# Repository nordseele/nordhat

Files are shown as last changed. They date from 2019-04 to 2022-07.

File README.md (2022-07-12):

# Nordhat & audio expansion board

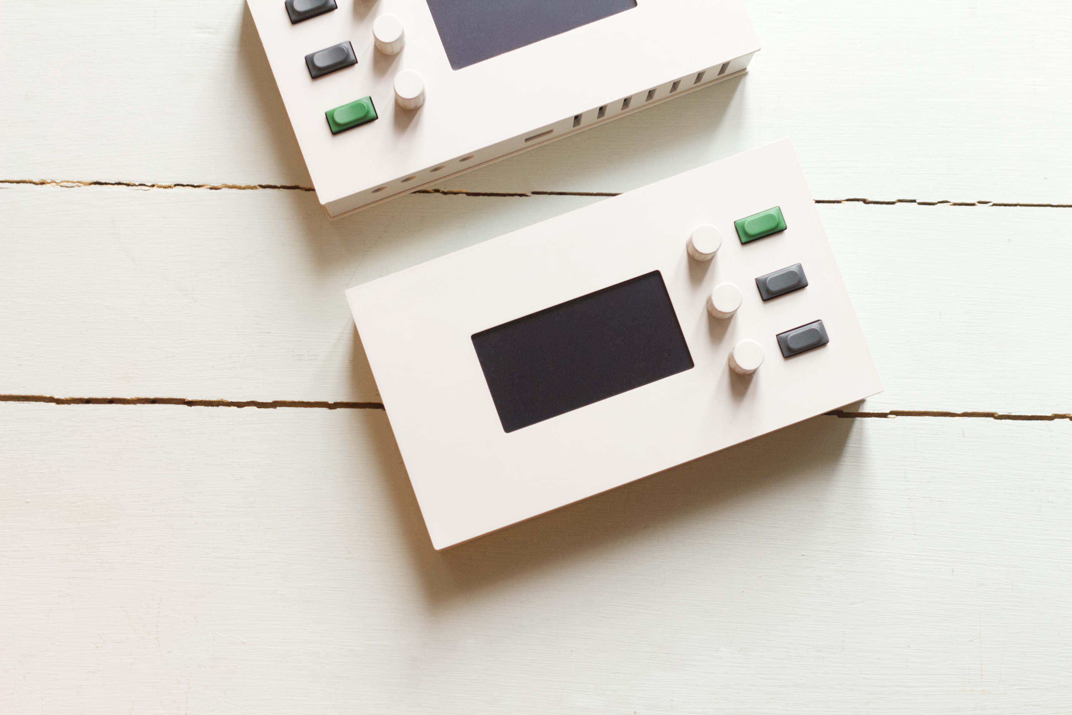
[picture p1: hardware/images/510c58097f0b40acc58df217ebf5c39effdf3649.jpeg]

Nordhat Rev 2 / custom "DR" prototypes

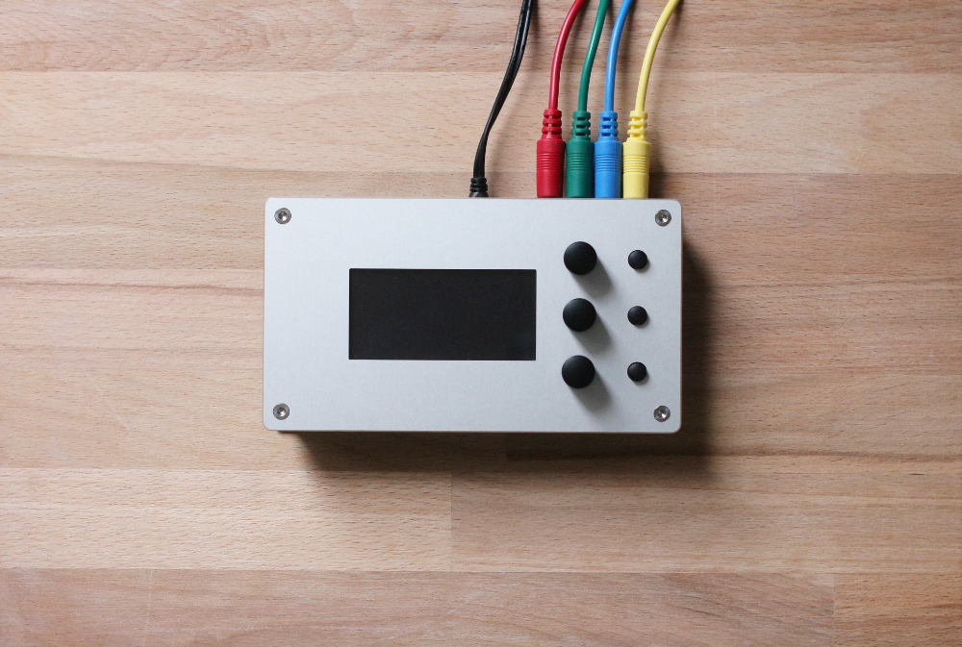
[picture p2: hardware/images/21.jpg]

Nordhat rev 1 prototype

Please read the [Notes](hardware/notes.md)

24/06/19: ***This board is probably NOT compatible with the new Raspberry Pi 4. The position of the Ethernet socket and USB sockets have changed in this latest revision of the PI and the Nordhat main PCB might not be adapted anymore.*** 

### Bill of material
[Main board](hardware/bom/BOM_mainboard_nordhat.csv)

[Expansion board](hardware/bom/BOM_expansion_board_nordhat.csv)

### Build

[Build](hardware/build.md) instructions

### Install

[Install](files/install.md) (Norns)

#### More infos and details

https://llllllll.co/t/norns-shield-case-designs/30347/333?u=nordseele

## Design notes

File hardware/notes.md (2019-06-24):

# Rev 3 Notes

## Before you start...

### Disclaimer
You must have a prior experience building electronic projects, soldering, etc. The tools (soldering iron, etc) used for building such electronic project can potentially be dangerous. This "DIY" project is not "beginner friendly". All the things learned and tested during the construction of this prototype are reflected here, these informations are provided "as is". If you have been provided with a set of PCB of this 'nordhat' or 'nornshat' (name of the early revisions) project, it is still a prototype and is still in development. You're building it at your own risk.

You'll find the references on the silkscreen and in the BOM and some additional tips and explanations on this page. If you choose another component than the one listed in the suggested BOM (encoders, jack connectors, etc) you should verify that the footprint and pin-out match, again you do this at your own risk.

***The actual Nordhat board is probably NOT compatible with the new Raspberry Pi 4. The position of the Ethernet socket and USB sockets have changed in this latest revision of the PI and the Nordhat main PCB might not be adapted anymore.***
---
# Hardware

### Dimensions

    Height: 84mm  
    Width: 150mm  
    Depth: 28mm  

## Headers and card to card connectors

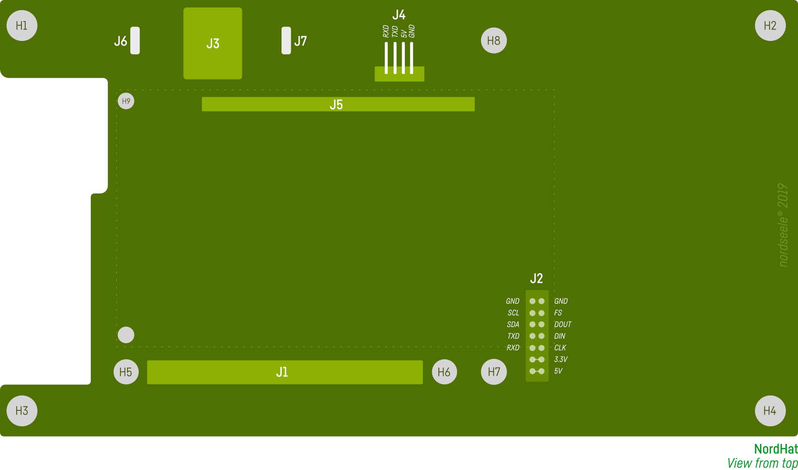
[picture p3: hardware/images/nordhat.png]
nordhat


#### J3, J7, J6 - The I2C section (middle/top of the board)
It's probably better to ***avoid soldering these connectors for now if you don't know what you're doing***, don't solder/order J3,J7,J6. This can be done later.

Edit : The I2C is already used for the DAC, this jack output will probably never be used simultaneously.

For now, this section has not been tested and has no utility. If you choose to solder the jack connector despite this recommendation, you should ***NEVER connect a midi jack or audio jack to this plug***. If you solder the stereo jack connector, it can be soldered either on top or on the bottom of the board (see silkscreen) but it's recommended to solder it on the bottom. For J7 and J6, cut two pins from a male 2.54 breakable pin strip like the reference suggested. (Order only one if you order the Adafruit 392, it’s a pack of 10 pieces)

#### J4 - UART 4 pins angled header
If you're not planning to use the UART header, don't solder/order J4, it can also be done later if you change your mind. If you solder it on, this header should be placed/soldered on top of the board (even if the silkscreen is printed on the bottom). This header can be used with the Adafruit 954 cable. You should ***NEVER CONNECT THE 5V pin if the Raspberry Pi is powered from USB.***

#### J2, 02x07 pins - expansion board header
You should solder this 14 positions 2 rows header ***before soldering the OLED*** display. It would be impossible or very difficult to solder this afterwards.
#### J5 - OLED Header
Cut twenty pins from a male 2.54 breakable pin strip (see Adafruit 392 pack, as mentioned above)

____

## OLED display

Solder the expansion board header (J2) before soldering the OLED display.

___
## Buttons and encoders

### Buttons / Key switches
We’re using low actuation force key switches, but feel free to use another actuation force, in the same APEM 5E series. Note that you could use the 5G series which has the same footprint and a larger choice of caps available, but you'll have to modify the cutout (larger holes) of the top panel in consequence.

### Button caps
1SS, the only caps available for the 5E series. They're available in **multiple colors** and height but 7mm is the recommended height. read the data sheet of the manufacturer to find out how to adjust the reference. Adjust height depending on the thickness of the panel etc. Try different heights eventually. ***These caps are made for the APEM 5E series ONLY***.

### Encoders
We’re using encoders without detent and without switch with T18 shaft. The shortest available in this series.
Use PEC11R-4015F-N0024 if you want a D-Shaft.
### Encoder knobs
Use what you want, modify your choice of encoder/shaft in consequence. The encoders knobs used on the "Nord Hat" prototype are not available to buy.  
___
## Standoffs

The NordHat prototype uses M3 rounded steel standoffs from the **WA-SMSI series made by Würth Elektronik** for H1, H2, H3, H4. The mounting holes have been specifically designed for these standoffs. The diameter of the holes is 4.4mm. If you do not use the WA-SMSI standoffs and prefer using some regular HEX standoffs instead, make sure they have a diameter of 6mm minimum. Use regular M2.5 hex standoffs for non-visible / internal mounting holes (H5, H6, H9, H8, H7)

It is recommended to use the following dimensions, these are the minimum heights. The Raspberry should not be in contact with the bottom panel. There should be 1 or 2mm of clearance between the panel and and the bottom of the RPI, especially if you're using an aluminium panel.

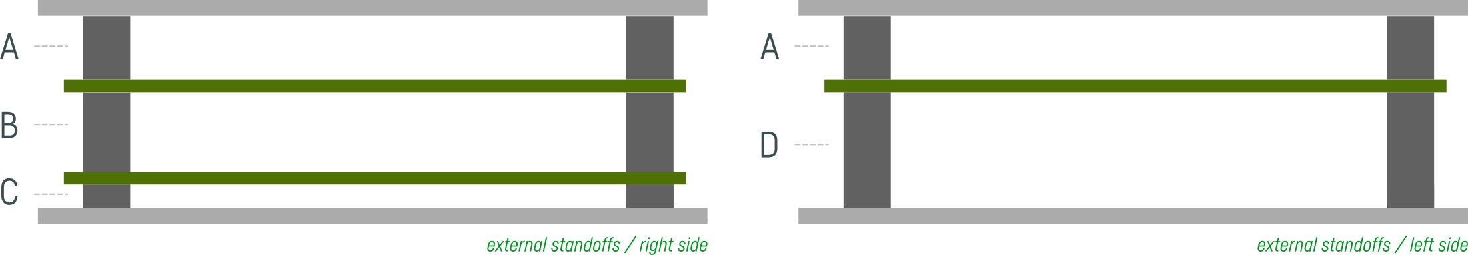
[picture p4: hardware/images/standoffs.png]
standoffs


| holes (h) | position | length  | type  | thread | quantity | sku
| :---: | :---: |:---: | :-----: | :---: | :---: | :----:
| 1, 2, 3, 4 | A | 7mm | FF  | M3 | 4 | WA-SMSI 9774070360R
| 1, 3 | D  | 15mm |  FF | M3  | 2 | WA-SMSI 9774150360R
| 5, 6  | RPI | 11mm  | FF  | M2.5 | 3 | use hex
| 9 | RPI | 11mm  | MF  | M2.5 | 3 | use hex
| 8, 7 | EXP | 10mm  | FF  | M2.5 | 2 | use hex
| 2, 4 | C | 3mm |  FF | M3  | 2 | WA-SMSI 9774030360R
| 2, 4 | B | 10mm |  FF | M3  | 2 | WA-SMSI 9774100360R

### Additional Hardware used for assembling the standoffs
Different possible combinations. Get these lines:
- ***Headless screws M3 8mm***   
- ***M2.5 6mm screws***
- ***Flat head screws M3 10mm and 6mm (Use normal head if your top panel doesn't have countersunk holes)***
- ***M2.5 nuts***

___
## Panels and screen protection
Two sets of files (dxf and fpd) are provided for making the top and bottom panels. They have countersunk holes and chamfer. If you want to make acrylic panels you'll have to edit the files to remove the chamfer and countersinks. The recommended thickness is 2mm. The viewing angle of the OLED display will be affected if the thickness is more than 2mm.

It is recommended to use a screen protection made of Perspex/ plexiglas. Less than 1mm thick. It is placed between the top panel and the display. Use double sided adhesive tape to attach it. The dimensions should be 4cm x 7cm maximum.
____

## GPIO

### Keys GPIO

- K1 : GPIO 06
- K2 : GPIO 27
- K3: GPIO 23

### Encoders GPIO

- E1A : GPIO 26  
  E1B : GPIO 13  

- E2A : GPIO 05  
  E2B : GPIO 22  

- E3A : GPIO 04  
  E3B : GPIO 17

### OLED display

- Reset : GPIO 25
- DC : GPIO 24

### UART

Using the Adafruit 954 cable:
- white lead TX
- green lead RX
- black lead GND
- ***DO NOT connect the red lead if the Pi is powered from USB !***

  `screen /dev/cu.usbserial* 115200`
____

___
##### Nordseele 2018 2019.

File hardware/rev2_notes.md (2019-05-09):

# Notes

These notes concern the Rev2 boards only (prior to Nordhat)

# Before you start...
### Disclaimer
You must have a prior experience building electronic projects, soldering, etc. The tools (soldering iron, etc) used for building such electronic project can be dangerous. This is not a beginner "DIY" project. All the things learned and tested during the construction of this prototype are reflected here, these informations are provided "as is". If you have been provided with a set of PCB of this 'nordhat' or 'nornshat' (name of the early revisions) project, it is still a prototype and is still in development. You're building it at your own risk.

You'll find the references on the silkscreen and in the BOM and some additional tips and explanations on this page. If you choose another component than the one listed in the suggested BOM (encoders, jack connectors, etc) you should verify that the footprint and pin-out match, again you do this at your own risk.

# Important advice

DO NOT solder the OLED display until all these steps are done. A certain chronology has to be respected. Some headers and standoffs are partially hidden under the OLED display. Before soldering this display, you need to solder the header ***J2*** and you need to mount a 11m standoff on ***H8*** (bottom).

---
# Hardware

### Dimensions

    Height: 84mm  
    Width: 150mm  
    Depth: 28mm  

## Headers and card to card connectors

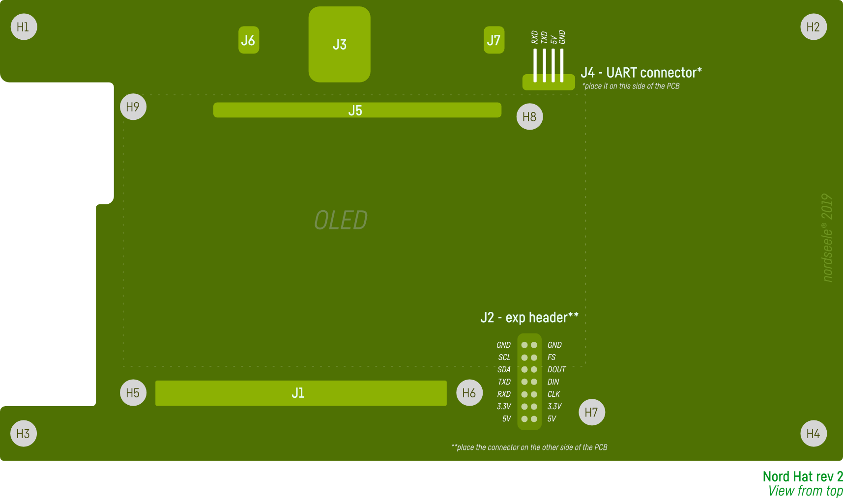
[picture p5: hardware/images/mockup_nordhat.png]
mockup headers and mounting holes


### J3, J7, J6 - The I2C section (middle/top of the board)
It's probably better to ***avoid soldering these connectors for now if you don't know what you're doing***, don't solder/order J3,J7,J6. This can be done later. For now, this section has not been tested and has no utility. If you choose to solder the jack connector despite this recommendation, you should ***NEVER connect a midi jack or audio jack to this plug***. If you solder the stereo jack connector, it can be soldered either on top or on the bottom of the board (see silkscreen) but it's recommended to solder it on the bottom. For J7 and J6, cut two pins from a male 2.54 breakable pin strip like the reference suggested. (Order only one if you order the Adafruit 392, it’s a pack of 10 pieces)

### J4 - UART 4 pins angled header
If you're not planning to use the UART header, don't solder/order J4, it can also be done later if you change your mind. If you solder it on, this header should be placed/soldered on top of the board (even if the silkscreen is printed on the bottom). This header can be used with the Adafruit 954 cable. You should ***NEVER CONNECT THE 5V pin if the Raspberry Pi is powered from USB.***

### J2, 02x07 pins - expansion board header
If you're planning to use the audio expansion board or if you need to access the GPIO )written on the bottom silkscreen) for any other purpose, ***you should solder this 14 positions 2 rows header before you solder the OLED display. It would be impossible or very difficult to solder this afterwards.***
### J5 - OLED Header
Cut twenty pins from a male 2.54 breakable pin strip (see Adafruit 392 pack, as mentioned above)

____

## OLED display

### A small modification of the NHD-2.7-12864WDW3 is required if you want to want to keep the oled display very low, flush to the main board PCB. If you prefer not doing this modification, you will have have to mount standoffs under the display. This Oled display has tiny black legs under it and these legs could be in contact with the expansion header.  

So you need to bend two of these legs (bottom right and top right when you face the display). If this modification is not done, one of these legs could possibly be in contact with the **J2** and the other one would hide the hole **h8** thus preventing the possibility of mounting a standoff there.

***Use some pliers and proceed very carefully ! Do this at your own risk***

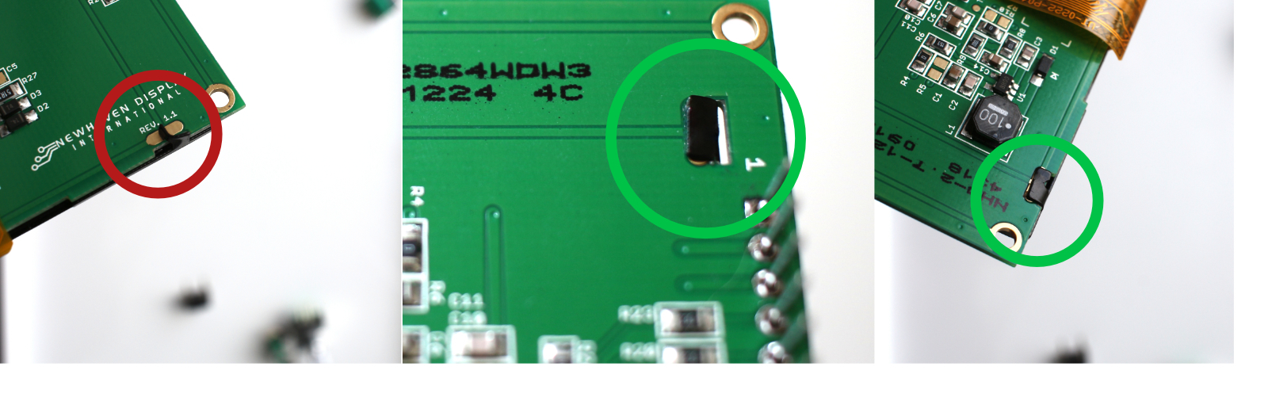
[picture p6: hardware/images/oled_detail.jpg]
bend the legs of the oled


### You should solder the various connectors and mount the standoff h8 BEFORE soldering the Oled display

___
## Buttons and encoders

### Buttons / Key switches
We’re using low actuation force key switches, but feel free to use another actuation force, in the same APEM 5E series. Note that you could use the 5G series which has the same footprint and a larger choice of caps available, but you'll have to modify the cutout (larger holes) of the top panel in consequence.

### Button caps
1SS, the only caps available for the 5E series. They're available in **multiple colors** and height. read the data sheet of the manufacturer to find out how to adjust the reference. Adjust height depending on the thickness of the panel etc. Try different heights eventually. ***These caps are made for the APEM 5E series ONLY***.

### Encoders
We’re using encoders without detent and without switch with T18 shaft. The shortest available in this series.
Use PEC11R-4015F-N0024 if you want a D-Shaft terminaison.
### Encoder knobs
Use what you want, modify your choice of encoder/shaft terminaison in consequence. The encoders knobs used on the "Nord Hat" prototype are not available to buy.  
___
## Standoffs
It is recommended to use the following dimensions, these are the minimum heights. The Raspberry should not be in contact with the bottom panel. There should be 1 or 2mm of clearance between the panel and and the bottom of the RPI, especially if you're using an aluminium panel.

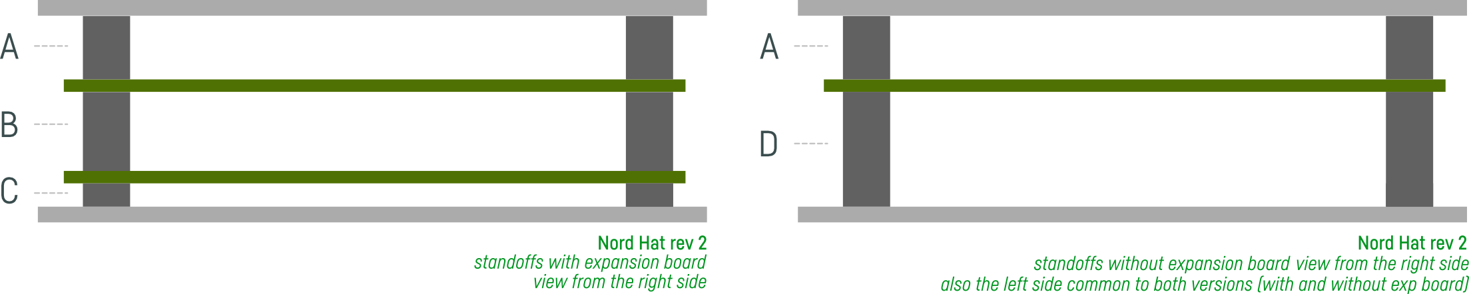
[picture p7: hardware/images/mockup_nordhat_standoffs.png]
mockup standoffs


### With expansion board

| holes (h) | position | length  | type  | thread | quantity |
| :---: | :---: |:---: | :-----: | :---: | :---: |
| 1, 2, 3, 4 | A | 7mm | FF  | M3 | 4 |
| 1, 3 | D  | 15mm |  FF | M3  | 2 |
| 5, 6, 9 | RPI | 11mm  | MF  | M2.5 | 3 |
| 8, 7 | EXP | 10mm  | FF  | M2.5 | 2 |
| 2, 4 | C | 3mm |  FF | M3  | 2 |
| 2, 4 | B | 10mm |  FF | M3  | 2 |

### Without expansion board
| holes (h) | position | length  | type  | thread | quantity |
| :---: | :---: |:---: | :-----: | :---: | :---: |
| 1, 2, 3, 4 | A | 7mm | FF  | M3 | 4 |
| 1, 2, 3, 4 | D | 15mm |  FF | M3  | 4 |
| 5, 6, 9 | RPI | 11mm  | MF  | M2.5 | 3 |
|8  | OPT  |  10mm | FF  | M2.5  |  1 |

> Even if you don't use an expansion board now, if you want to attach one someday it is recommended to mount the ***H8 standoff*** (noted OPT in the table above). It won't be possible to attach it once the OLED is soldered on. This has to be done before soldering the OLED.

### Hardware used for assembling the standoffs
Different possible combinations. Get these lines:
- ***Headless screws M3 8mm***    
- ***Flat head screws M3 10mm and 6mm (Use normal head if your top panel doesn't have countersunk holes)***
- ***M2.5 nylon washers***  
- ***M2.5 nuts***

#### More infos about the standoffs
The Nord Hat prototype use rounded  steel standoffs of the **WA-SMSI series made by Würth Elektronik**. If you wish to use them, you will need to drill some mounting holes of the PCB (diameter 4.4mm H1, 2, 3, 4). Do this at your own risk even though there are no traces passing too close from these holes and there's an additional margin of error of 1mm. Beware if you order these standoffs, they have a thinner 1mm high ring on top, the height of this ring supposed to be inserted into the mounting hole is not taken into account in the reference, that means that the WA-SMSI 15mm standoff is actually 15mm + 1mm (16mm). Same goes for all the references of this series (see data sheet of the manufacturer for more information).
___
## Panels and screen protection
Two sets of files (dxf and fpd) are provided for making the top and bottom panels. They have countersunk holes and chamfer. If you want to make acrylic panels you'll have to edit the files to remove the chamfer and countersinks. The recommended thickness is 2mm. The viewing angle of the OLED display will be affected if the thickness is more than 2mm.

It is recommended to use a screen protection made of Perspex/ plexiglas. Less than 1mm thick. It is placed between the top panel and the display. Use double sided adhesive tape to attach it. The dimensions should be 4cm x 7cm maximum.

##### Nordseele 2018 2019.

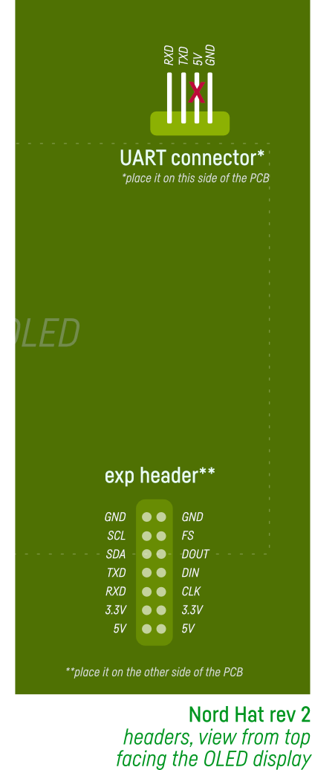
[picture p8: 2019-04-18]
hardware/images/mockup_nordhat_headers.png

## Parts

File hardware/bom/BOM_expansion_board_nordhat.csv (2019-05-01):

Id | Designator | Package | Quantity | Designation | Manufacturer ref
3 | J6 | sj1-3523 | 1 | Stereo jack 3.5 | sj1-3523
4 | J4,J5,J2,J3 | MJ_3536 | 4 | Mono jack 3.5 | MJ-3536
6 | J1 | Header_2x07_P2.54mm_Vertical | 1 | Connector | 215307-7
5 | Y1 | Crystal_HC49 | 1 | 12.288MHz | Abracon ABLS2-12.288MHZ-D4Y-T
7 | U2 | Voltage regulator | 1 | ADP150AUJZ-3.3-R7 | ADP150AUJZ-3.3-R7
8 | C17,C2,C3 | Electrolytic cap | 3 | 10uF | EEE-1EA100WR
9 | C7,C8 | Electrolytic cap | 2 | 220uF | EEEFTE221XAP
10 | C12,C13,C14,C15 | Electrolytic cap | 4 | 1u | EEE1HA010SR
11 | C1,C4,C5,C6,C11,C27,C19 | Ceramic cap_0805 | 7 | 100n | 08051C104J4T4A
13 | C16,C18 | Ceramic cap_0805 | 2 | 18p | C0805X180J5GAC7800
1 | C10,C9 | Ceramic cap_0805 | 2 | 220p | 885012007059
14 | R1,R2,R3,R4 | resistor_0805, 1% | 4 | 220R | CRCW0805220RFKEAC
2 | R10,R5,R6,R9 | resistor_0805, 1% | 4 | 5.6K | CRCW08055K60FKEAC
15 | R7,R8,R11,R12 | resistor_0805, 1% | 4 | 47K | CRCW080547K0FKEAC
16 | R13,R14 | resistor_0805, 1% | 2 | 100R | CRCW0805100RFKEAC
12 | U1 | SSOP-28 | 1 | WM8731 DAC | WM8731SEDS/RV
17 |  | Standoffs | <—> | See notes | See notes.md

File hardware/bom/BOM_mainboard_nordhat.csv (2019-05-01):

Id | Designator | Package | Quantity | Designation | Supplier and ref | Notes
 | Switches | SW_MEC_5ETH920Q | 3 | Switches | APEM 5ETH920Q | See notes.md
 | Encoders | RotaryEncoder_Bourns_Vertical | 3 | Rotary_Encoders | PEC11R-4015K-N0024 (T18) | PEC11R-4015F-N0024 for D-shaft See notes.md
 | J5 | NHD-2.7-12864WDW3_nosilk | 1 | OLED display | NHD-2.7-12864WDW3
 | J3 | SJ3523_stereo | 1 | I2C stereo jack (*) | SJ1-3523N | See notes.md
 | J7,J6 | Header 1x02_P2.54mm_Vertical | 2 | I2C jumpers (*) | Adafruit 392 | See notes.md
 | J4 | Header 1x04_P2.54mm_angled | 1 | UART header | WURTH 61300411021 | See notes.md
 | J2 | Header_2x07_P2.54mm_Vertical | 1 | Expansion header | TSW-107-07-G-D | See notes.md
 | J1 | Header_2x20_P2.54mm_Vertical | 1 | RPi GPIOS header | ADAFRUIT 2222 | See notes.md
 | J5 (B) | Header 1x20_P2.54mm_Vertical | 1 | Oled header | Adafruit 392 | See notes.md
 | D4,D3,D2,D1 | D_SOD-123 | 4 | 1N4148 | 1N4148W-7-F
 | C1,C2,C3,C4,C5,C6,C7,C8,C9 | Ceramic_capacitors 0805 | 9 | 0.1uF (100n) | 08051C104J4T4A
 | R4,R5,R6,R9,R10,R13,R14,R17,R18 | Resistors 0805_1% | 9 | 10k | CRCW080510K0FKEAC
 | R1,R2 | Resistors 0805_1% | 2 | 4.7k | CRCW08054K70FKEA
 | Button caps |  |  | Button caps | APEM 1SS09-12.0 | See notes.md
 | Encoder knobs |  |  | Undetermined | Undetermined | See notes.md
 | Raspberry Pi | Raspberry Pi 3 Model B+
 | Standoffs | Undetermined | <—> | Standoffs | See notes | See notes.md
 | The asterisk means that the corresponding line is probably optional. Read the corresponding section in « notes.md »

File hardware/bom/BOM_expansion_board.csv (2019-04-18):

Id | Designator | Package | Quantity | Designation | Manufacturer ref
3 | J6 | sj1-3523 | 1 | Stereo jack 3.5 | sj1-3523
4 | J4,J5,J2,J3 | MJ_3536 | 4 | Mono jack 3.5 | MJ-3536
6 | J1 | Header_2x07_P2.54mm_Vertical | 1 | Connector | 215307-7
5 | Y1 | Crystal_HC49 | 1 | 12.288MHz | Abracon ABLS2-12.288MHZ-D4Y-T
7 | U2 | Voltage regulator | 1 | ADP150AUJZ-3.3-R7 | ADP150AUJZ-3.3-R7
8 | C17,C2,C3 | Electrolytic cap | 3 | 10uF | EEE-1EA100WR
1 | C10,C9 | Ceramic cap_0603 | 2 | 220p | CC0603JRNPO9BN221
9 | C7,C8 | Electrolytic cap | 2 | 220uF | EEEFTE221XAP
10 | C12,C13,C14,C15 | Electrolytic cap | 4 | 1u | EEE1HA010SR
11 | C1,C4,C5,C6,C11,C27,C19 | Ceramic cap_0603 | 7 | 100n | C0603C104J3RAC7411
13 | C16,C18 | Ceramic cap_0603 | 2 | 18p | C0603C180K5RACAUTO
14 | R1,R2,R3,R4 | resistor_0603, 1% | 4 | 220R | CRCW0603220RFKEAC
2 | R10,R5,R6,R9 | resistor_0603, 1% | 4 | 5.6K | CRCW06035K60FKEAC
15 | R7,R8,R11,R12 | resistor_0603, 1% | 4 | 47K | CRCW060347K0JNEAC
16 | R13,R14 | resistor_0603, 1% | 2 | 100R | CRCW0603100RFKEAC
12 | U1 | SSOP-28 | 1 | WM8731 DAC | WM8731SEDS/RV
17 |  | Standoffs | <—> | See notes | See notes.md

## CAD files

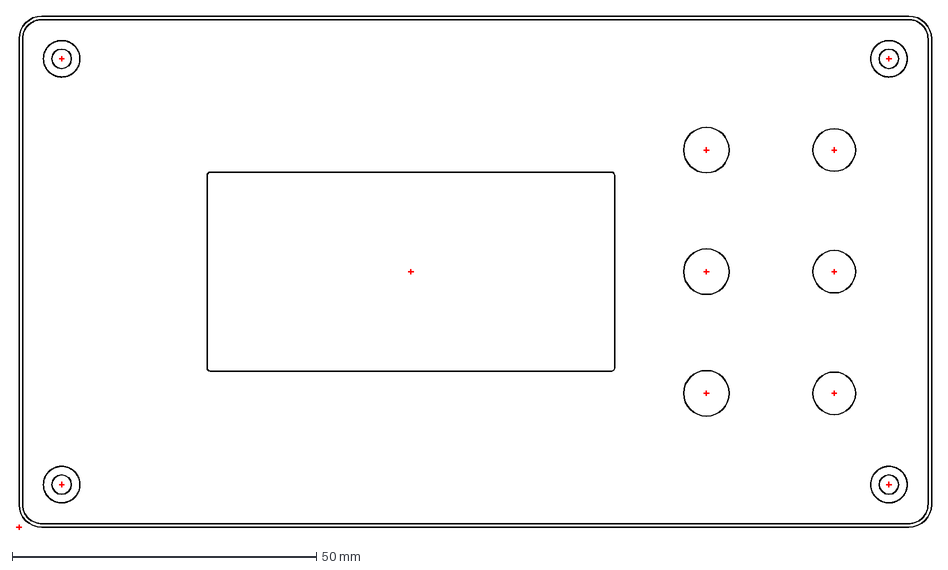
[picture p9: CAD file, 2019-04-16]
hardware/panels/nordhat_top_alu.dxf
150.4 x 84.4 mm

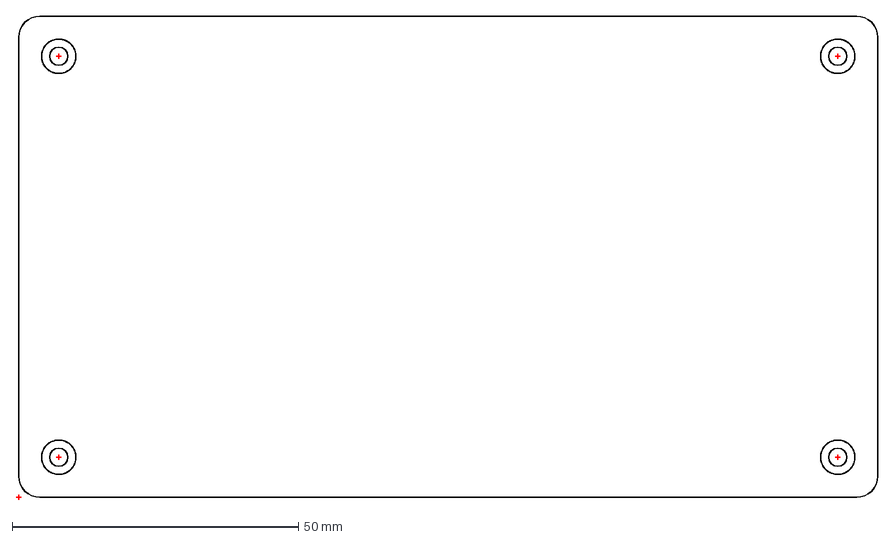
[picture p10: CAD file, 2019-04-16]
hardware/panels/nordhat_bottom_alu.dxf
150.4 x 84.4 mm

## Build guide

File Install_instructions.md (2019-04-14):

# Preparing the Raspberry PI

### Download raspbian stretch lite
https://www.raspberrypi.org/downloads/raspbian/  
(tested with 2018-11-13 release)

### Flash raspbian lite to the sdcard
Use balenaEtcher - https://www.balena.io/etcher/ for this.

### SSH configuration

 Create a **wpa-supplicant.conf** file for your network and copy the file to the root of the ***boot*** volume

    country=fr (your country)
    update_config=1
    ctrl_interface=/var/run/wpa_supplicant
    network={
      scan_ssid=1
      ssid="Name of your router"
      psk="Your key"
    }

Open a terminal and type paste the following commands, one line at a time:

    cd /volumes && ls
    cd boot && touch ssh

Move the **wpa-supplicant.conf** file you've created to the root of the SD card and then unmount the sd card.

### Mount the SD card and boot the Raspberry Pi

Find the IP of your Raspberry Pi using a software like Lanscan and
   generate a key (replace XX with the IP of the RPI).  
Open a terminal and enter the following command (XX is the last two digits of the PI's IP).  
`ssh-keygen -R 192.168.1.XX`

Connect via SSH. `ssh pi@192.168.1.XX` The password is ***raspberry***

### RPI adjustments
Enter the following commands in a terminal, edit if needed (country etc).

`sudo raspi-config nonint do_hostname norns`  
`sudo raspi-config nonint do_spi 0`  
`sudo raspi-config` (change wifi country in the "Localization" menu, this is crucial)  
`sudo raspi-config nonint do_expand_rootfs`  
`sudo su`  
`passwd pi` ***(sleep)***  
`sudo reboot`  
`ssh keygen -R norns.local`  
`sudo passwd root` ***(sleep)***  
`sudo nano /etc/ssh/sshd_config` ***("PermitRootLogin" needs to be set to "yes" and uncomment the line)***  
`sudo reboot`  
`ssh root@norns.local`  
`usermod -l we -d /home/we -m pi`   
`groupmod --new-name we pi`  
`exit`  
`ssh we@norns.local`  
`sudo passwd -l root` ***(sleep)***
`sudo nano /etc/sudoers.d/010_pi-nopasswd` ***(change pi to we)***  
`sudo reboot`

# Linux & Kernel

## Run updates install git, build dependencies, etc
Reminder: the password is ***sleep***  

    ssh we@norns.local
	sudo apt-get update
    sudo apt-get dist-upgrade -y
    sudo apt-get install vim git bc i2c-tools -y
    git clone https://github.com/nordseele/nornsHat_install.git
    cd nornsHat_install && ./hat_prepare.sh

### Testing the ssd1322
Now we're going to test the display. If your soldering is fine and if the kernel has been built correctly, you should see the console displayed on the OLED screen but first we need to do this :

    sudo modprobe fbtft_device custom name=fb_ssd1322 width=128 height=64 speed=16000000 gpios=reset:25,dc:24
    con2fbmap 1 1

# Norns
    cd /home/we/nornsHat_install &&./hat_packages.sh

You will be disconnected and the device will reboot. Reconnect in a new window.  

    cd /home/we/nornsHat_install &&./hat_install.sh
Answer ***yes (y)*** to "enable realtime priority"

# Wifi network  
*Do this manually, too risky to put it in the script.*

    ssh we@norns.local
    sudo cp ~/norns-linux-bits/interfaces /etc/network/interfaces
    sudo mv /etc/wpa_supplicant/wpa_supplicant.conf /etc/wpa_supplicant/wpa_supplicant_bak.conf

And reboot (with command line if possible).  
On the Raspberry pi, navigate to System -> Wifi and add your network manually.

___
#### Notes
* We need to find another way to connect, entering long password with the encoders is difficult.
* You might encounter some issues with the encoders until the process is complete, wifi setup etc.
* CPU spikes appears as soon as a USB card is connected (??)

___
#### Using NornsHat without USB soundcard and without audio expansion board

`sudo nano /boot/config.txt`

      # Enable audio (loads snd_bcm2835)
      dtparam=audio=on
`sudo nano /etc/modprobe.d/raspi-blacklist.conf`
and comment out "blacklist snd_bcm2835"

`sudo nano /etc/systemd/system/norns-jack.service`
and replace 128 with 256.

`amixer cset numid=3 1`

`sudo reboot`

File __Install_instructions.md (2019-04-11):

<i>These instructions are provided by Okyeron 🙌  and edited by Nordseele for the NornsHat</i>
<h1 id="preparing-the-raspberry-pi-sd-card">Preparing the Raspberry PI SD card</h1>
<h2 id="download-raspbian-stretch-lite">Download raspbian stretch lite</h2>
<p><a href="https://www.raspberrypi.org/downloads/raspbian/">https://www.raspberrypi.org/downloads/raspbian/</a><br>
(tested with 2018-11-13 release)</p>
<h2 id="flash-raspbian-lite-to-the-sdcard">Flash raspbian lite to the sdcard</h2>
<p>Use balenaEtcher - <a href="https://www.balena.io/etcher/">https://www.balena.io/etcher/</a> for this. (approx. 5min)</p>
<h2 id="sssh-configuration-or-use-the-uart-header">Sssh configuration (or use the UART header)</h2>
<ol>
<li>
<p><strong>Create a file in Atom</strong> and save it as <strong>wpa-supplicant.conf</strong></p>
<p>The file looks like this:</p>
<blockquote>
<pre><code>country=fr (your country)
update_config=1
ctrl_interface=/var/run/wpa_supplicant
network={
scan_ssid=1
ssid="Name of your router"
psk="Your key"
}
</code></pre>
</blockquote>
</li>
<li>
<p>Then in a terminal :</p>
<pre><code>cd /volumes &amp;&amp; ls
cd boot &amp;&amp; touch ssh
</code></pre>
</li>
<li>
<p>Copy the <strong>wpa-supplicant.conf</strong> file you’ve created to the root of<br>
the SD card</p>
</li>
<li>
<p>Unmount the volume “Boot”,load the SD card in the Raspberry Pi and<br>
power it on.</p>
</li>
<li>
<p>Find the IP of your Raspberry Pi using a software like Lanscan and<br>
generate a key (replace XX with the IP of the RPI)</p>
<pre><code>ssh-keygen -R 192.168.1.XX
</code></pre>
</li>
<li>
<p>Connect via SSH</p>
<p><code>ssh pi@192.168.1.XX</code> (password: raspberry)</p>
</li>
</ol>
<h3 id="rpi-adjustments">4 - RPI adjustments</h3>
<ol>
<li>
<p><code>sudo raspi-config</code></p>
<blockquote>
<p>Password : sleep<br>
Network : Hostname (norns)<br>
Interfacing : SSH (on)<br>
Interfacing : Spi (on)<br>
Interfacing : I2s (on)<br>
Advanced : Expand File System<br>
Localization : (en-US-UTF8, US-UTF8)<br>
Locallization : wifi country &gt; your country<br>
Localization : timezone &gt; your timezone</p>
</blockquote>
</li>
<li>
<p>Reboot. (<code>sudo reboot</code>)</p>
</li>
<li>
<p>Login again</p>
<p><code>ssh pi@192.168.1.XX</code> (password: sleep)</p>
</li>
<li>
<p>Change the default user name</p>
<pre><code>sudo passwd root  (password: sleep)
sudo nano /etc/ssh/sshd_config
</code></pre>
</li>
<li>
<p>Find this line: <code>#PermitRootLogin prohibit-password</code> Edit it so it<br>
reads : <code>PermitRootLogin yes</code></p>
</li>
<li>
<p>Close and save the file.</p>
</li>
<li>
<p>Reboot</p>
</li>
<li>
<p>Login as root</p>
<pre><code>ssh root@192.168.1.XX (password: sleep)
</code></pre>
</li>
<li>
<p>Then <code>usermod -l we -d /home/we -m pi</code></p>
<p>and <code>groupmod --new-name we pi</code></p>
</li>
<li>
<p>Exit, and this time login as <code>we</code></p>
<pre><code>ssh we@192.168.1.XX (password: sleep)

sudo passwd -l root
</code></pre>
</li>
<li>
<p>Disable need for passwd with sudo   (sudoers filename will vary -<br>
tab to autocomplete or <code>ls /etc/sudoers.d/</code> to check the filename)</p>
<pre><code>sudo nano /etc/sudoers.d/010...  
</code></pre>
<p>Change ‘<strong>pi</strong>’ to ‘<strong>we</strong>’</p>
</li>
<li>
<p>Save and exit (ctrl + x -&gt; y)</p>
</li>
</ol>
<h1 id="linux--kernel">Linux &amp; Kernel</h1>
<h2 id="run-updates-install-git-build-dependencies-etc">Run updates install git, build dependencies, etc</h2>
<p>Enter the following commands one by one in the terminal.</p>
<pre><code>cd ~
sudo apt-get update
sudo apt-get dist-upgrade
sudo apt-get install vim git bc i2c-tools
sudo apt-get -y install libncurses5-dev
git clone https://github.com/okyeron/norns-linux-bits.git
git clone --depth 1 --branch rpi-4.14.y-rt https://github.com/raspberrypi/linux     
cd linux
git checkout 22bb67b8e2e809d0bb6d435c1d20b409861794d2
cp ~/norns-linux-bits/drivers-staging-fbtft/* /home/we/linux/drivers/staging/fbtft/
cp ~/norns-linux-bits/arch-arm-configs/bcm2709_defconfig/home/we/linux/arch/arm/configs/bcm2709_defconfig
cp ~/norns-linux-bits/.config /home/we/linux/.config
</code></pre>
<h2 id="building-the-kernel">Building the kernel</h2>
<ol>
<li>
<h3 id="setting-the-scene.">Setting the scene.</h3>
<pre><code> cd ~/linux
 export KERNEL=kernel7
 make mrproper
 make bcm2709_defconfig
 make modules_prepare
</code></pre>
</li>
<li>
<h3 id="quick-verification-for-the-ssd1322">Quick verification for the ssd1322</h3>
<p>At this step we need to ensure that the module for the SSD1322 display<br>
will actually be loaded.</p>
<pre><code>make menuconfig
</code></pre>
<h5 id="and-dive-into-the-menus...">And dive into the menus…</h5>
<blockquote>
<p><em>Device Drivers  —&gt; Staging Drivers —&gt; Support for small TFT LCD display modules  —&gt; <strong>SSD1322 driver</strong></em></p>
</blockquote>
<p>There should be a letter <strong>M</strong> next to this line. If it’s not there type <strong>M</strong> and answer yes or hit enter. Don’t forget to hit <strong>save</strong>, the filename is <strong>.config</strong></p>
</li>
<li>
<h3 id="compiling-the-kernel">Compiling the kernel</h3>
<p>The following part will take quite a long time (approx. 1h30)</p>
<pre><code>make -j4 zImage modules dtbs
sudo make modules_install
sudo cp arch/arm/boot/dts/*.dtb /boot/
sudo cp arch/arm/boot/dts/overlays/*.dtb* /boot/overlays/
sudo cp arch/arm/boot/dts/overlays/README /boot/overlays/
sudo cp arch/arm/boot/zImage /boot/$KERNEL.img
sudo reboot
</code></pre>
</li>
<li>
<h3 id="testing-the-ssd1322">Testing the ssd1322</h3>
<p>Now we’re going to test the display. If your soldering is fine and if the kernel has been built correctly, you should see the console displayed on the OLED screen but first we need to do this :</p>
<pre><code>sudo modprobe fbtft_device custom name=fb_ssd1322 width=128 height=64 speed=16000000 gpios=reset:25,dc:24
con2fbmap 1 1
</code></pre>
</li>
</ol>
<h1 id="package-installs">Package installs</h1>
<h5 id="enter-these-commands-one-by-one">Enter these commands one by one</h5>
<pre><code>curl https://keybase.io/artfwo/pgp_keys.asc | sudo apt-key add -
echo "deb https://package.monome.org/ stretch main" | sudo tee /etc/apt/sources.list.d/norns.list
</code></pre>
<pre><code>sudo apt update
sudo apt install --no-install-recommends jackd2
sudo apt-get install libboost1.62-dev
sudo apt-get install libjack-jackd2-dev
sudo apt install libmonome-dev libnanomsg-dev supercollider-language supercollider-server supercollider-supernova supercollider-dev liblua5.3-dev libudev-dev libevdev-dev liblo-dev libcairo2-dev liblua5.3-dev libavahi-compat-libdnssd-dev libasound2-dev
sudo apt install dnsmasq
sudo apt install sc3-plugins ladspalist
sudo apt install usbmount
sudo apt-get install alsa-utils
sudo apt-get install libi2c-dev
</code></pre>
<p>Finally,  <code>sudo nano /lib/systemd/system/systemd-udevd.service</code>   and change<br>
<code>slave</code> to <code>shared</code></p>
<h1 id="audio">Audio</h1>
<ol>
<li>
<h3 id="edit--raspi-blacklist.conf">Edit  raspi-blacklist.conf</h3>
<pre><code>sudo nano /etc/modprobe.d/raspi-blacklist.conf  
</code></pre>
<p>Add</p>
<blockquote>
<pre><code>blacklist snd_bcm2835
</code></pre>
</blockquote>
</li>
<li>
<h3 id="createedit-asound.conf">Create/edit asound.conf</h3>
<pre><code>sudo nano /etc/asound.conf  
</code></pre>
<p>Add</p>
<blockquote>
<pre><code>pcm.!default  {  
 type hw card 0  
}  

ctl.!default {  
type hw card 0  
}  
</code></pre>
</blockquote>
</li>
<li>
<h3 id="edit-alsa.conf">Edit alsa.conf</h3>
<pre><code>sudo nano /usr/share/alsa/alsa.conf   
</code></pre>
<h5 id="comment-out">Comment out</h5>
<blockquote>
<pre><code>#pcm.front cards.pcm.front
#pcm.rear cards.pcm.rear
#pcm.center_lfe cards.pcm.center_lfe
#pcm.side cards.pcm.side
#pcm.surround21 cards.pcm.surround21
#pcm.surround40 cards.pcm.surround40
#pcm.surround41 cards.pcm.surround41
#pcm.surround50 cards.pcm.surround50
#pcm.surround51 cards.pcm.surround51
#pcm.surround71 cards.pcm.surround71
#pcm.iec958 cards.pcm.iec958
#pcm.hdmi cards.pcm.hdmi
#pcm.modem cards.pcm.modem
#pcm.phoneline cards.pcm.phoneline
</code></pre>
</blockquote>
</li>
</ol>
<h1 id="network-manager">Network Manager</h1>
<p>Make a quick change to network interfaces so network-manager does not take over wifi</p>
<p><strong>NOTE</strong> - <em>At the end of the network-manager install you will get kicked of off wifi and will be assigned a new IP address. You will want to have a keyboard and monitor attached here to login directly and get your IP address with <code>ifconfig</code> - or you can fake it by checking a tool like <a href="https://itunes.apple.com/us/app/lanscan/id472226235">LanScan</a> to find the device on your network.</em> <strong>Also</strong> - <em>the IP address will likely change each time you reboot.</em> <em>We will fix this at the very end of the install.</em></p>
<p><code>sudo nano /etc/network/interfaces</code></p>
<p>Add this:</p>
<blockquote>
<p><code>auto wlan0</code></p>
</blockquote>
<p>Then install network-manager and reboot</p>
<pre><code>sudo apt install network-manager
</code></pre>
<h1 id="norns-setup">Norns setup</h1>
<ol>
<li>
<h3 id="download-norns-image">Download norns image</h3>
<pre><code>git clone https://github.com/monome/norns-image.git  
cd norns-image
</code></pre>
</li>
<li>
<h3 id="edit-a-few-config-files">Edit a few config files</h3>
<p>Start by entering  this command <code>nano setup.sh</code> and comment out<br>
(<em>put a # at the beginning of)</em>  the following line:</p>
<blockquote>
<pre><code>#sudo apt install network-manager dnsmasq-base midisport-firmware
</code></pre>
</blockquote>
<h5 id="comment-out-dhcpinterfaces-copies-so-it-does-not-hose-your-wifi-when-you-install">Comment out dhcp/interfaces copies so it does not hose your wifi when you install</h5>
<blockquote>
<pre><code>#sudo cp config/interfaces /etc/network/interfaces
</code></pre>
</blockquote>
<p>Now edit <code>nano config/norns-matron.service</code></p>
<p>And replace the line that starts with <em>ExecStart</em> with this one</p>
<pre><code>ExecStart=/home/we/norns/build/ws-wrapper/ws-wrapper ws://*:5555 /home/we/norns/build/matron/matron -f/dev/fb1
</code></pre>
<p>And now  <code>nano scripts/init-norns.sh</code>  and comment out the following lines (You might want to comment out the mixer line if you’re using a USB soundcard.)</p>
</li>
</ol>
<blockquote>
<pre><code>    #sudo i2cset -y 1 0x28 0x00
    #sudo i2cset -y 1 0x28 0x40
    #sudo i2cset -y 1 0x29 0x00
    #sudo i2cset -y 1 0x29 0x40
</code></pre>
</blockquote>
<ol start="3">
<li>
<h3 id="create-norns-init.service">Create norns-init.service</h3>
sudo nano/etc/systemd/system/norns-init.service</li>
</ol>
<blockquote>
<pre><code>    [Unit]
    Description=norns-init
    [Service]
    Type=oneshot
    ExecStart=/bin/sh -c "/bin/echo -n performance &gt; /sys/devices/system/cpu/cpu0/cpufreq/scaling_governor"
    [Install]
    WantedBy=norns.target
</code></pre>
</blockquote>
<ol start="4">
<li>
<h3 id="add-norns-init-to-norns.target">Add norns-init to norns.target</h3>
<p><code>nano config/norns.target</code> and add above <em>norns-jack.service</em></p>
<pre><code>Requires=norns-init.service
</code></pre>
</li>
<li>
<h3 id="now-run-setup.sh">Now run <a href="http://setup.sh">setup.sh</a></h3>
<p><code>./setup.sh</code></p>
</li>
<li>
<h3 id="install-norns">Install norns</h3>
<pre><code>cd ~
git clone https://github.com/monome/norns.git
cd norns
./waf configure
./waf
</code></pre>
</li>
<li>
<h3 id="run-sclang">Run sclang</h3>
<p><code>sclang</code>  and exit with (ctrl + z)</p>
</li>
<li>
<h3 id="install-sc">Install SC</h3>
<pre><code>cd sc
./install.sh
</code></pre>
</li>
<li>
<h3 id="framebuffer-setup-for-oled">Framebuffer setup for oled</h3>
<p>Edit <em><a href="http://matron.sh">matron.sh</a></em> to add <em>-f/dev/fb1</em></p>
<p><code>sudo nano ~/norns/matron.sh</code></p>
<blockquote>
<pre><code>./build/ws-wrapper/ws-wrapper ws://*:5555 ./build/matron/matron -f/dev/fb1
</code></pre>
</blockquote>
</li>
</ol>
<h1 id="dust-and-maiden">Dust and Maiden</h1>
<p>Get dust from <a href="https://monome.nyc3.digitaloceanspaces.com/norns190405.tgz">updater</a> and transfer the folder over SFTP (using Filezilla for example) to the <em>we</em> folder on the Raspberry Pi.</p>
<p>Get maiden from github releases:<br>
<a href="https://github.com/monome/maiden/releases">https://github.com/monome/maiden/releases</a></p>
<pre><code>cd ~
wget https://github.com/monome/maiden/releases/download/v0.13/maiden-v0.13.tgz
tar -xvf maiden-v0.13.tgz
rm maiden-v0.13.tgz
</code></pre>
<h1 id="compiling-overlays">Compiling Overlays</h1>
<p>The .dts files needs to be compiled to .dtbo and then the .dtbo needs to be copied to <code>/boot/overlays/</code></p>
<p><strong>(NornsHat REV2 users only)</strong></p>
<pre><code>cd~
git clone https://github.com/nordseele/nornsHat_install_files.git
cd nornsHat_install_files
</code></pre>
<ol>
<li>
<h3 id="norns-buttons-encoders-overlay">Norns-buttons-encoders-overlay</h3>
<p><code>sudo dtc -W no-unit_address_vs_reg -@ -I dts -O dtb -o /boot/overlays/norns-buttons-encoders.dtbo norns-buttons-encoders-overlay.dts</code></p>
</li>
<li>
<h3 id="ssd1322">Ssd1322</h3>
<p><code>sudo dtc -W no-unit_address_vs_reg -@ -I dts -O dtb -o /boot/overlays/ssd1322-spi.dtbo ssd1322-spi-overlay.dts</code></p>
</li>
<li>
<h3 id="edit-config.txt">Edit config.txt</h3>
<p>Add the reference to the overlays to  <em>/boot/config.txt</em><br>
<code>sudo nano /boot/config.txt</code></p>
<pre><code># Buttons and encoders
dtoverlay=norns-buttons-encoders
dtoverlay=ssd1322-spi
</code></pre>
</li>
</ol>
<h1 id="network--wifi">Network / Wifi</h1>
<h3 id="do-this-after-youre-screen-is-up-and-running-properly">DO THIS AFTER YOU’RE SCREEN IS UP AND RUNNING PROPERLY</h3>
<p>Reset <code>/etc/network/interfaces</code>  to norns default</p>
<pre><code>sudo cp ~/norns-linux-bits/interfaces /etc/network/interfaces
</code></pre>
<p>Rename /etc/wpa_supplicant/wpa_supplicant.conf to something else and reboot.<br>
this should get network manager to take over</p>
<pre><code>mv /etc/wpa_supplicant/wpa_supplicant.conf /etc/wpa_supplicant/wpa_supplicant_bak.conf
</code></pre>
<p>Reboot</p>
<p>At this point you will want to login to your wifi from the device screen so network manager remembers your wifi info.</p>

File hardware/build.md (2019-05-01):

# Build instructions
Please read the [notes](notes.md) if you have not already done so.

### Bill of material
[Main board](bom/BOM_mainboard_nordhat.csv)

[Expansion board](bom/BOM_expansion_board_nordhat.csv)

#### 1) SMD components
Start by soldering the SMD components on both boards. Clean up with IPA if necessary.

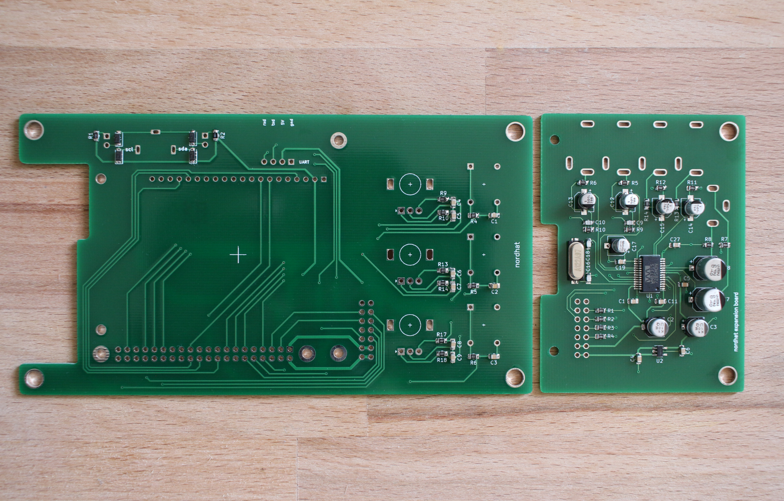
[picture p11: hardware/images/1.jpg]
SMD components


#### 2) Through-hole components

Solder the buttons, the encoders, the expansion header and the UART header.

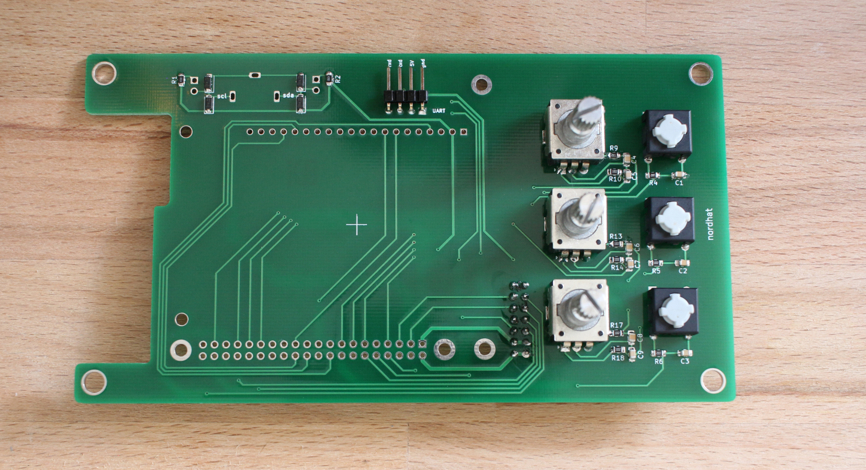
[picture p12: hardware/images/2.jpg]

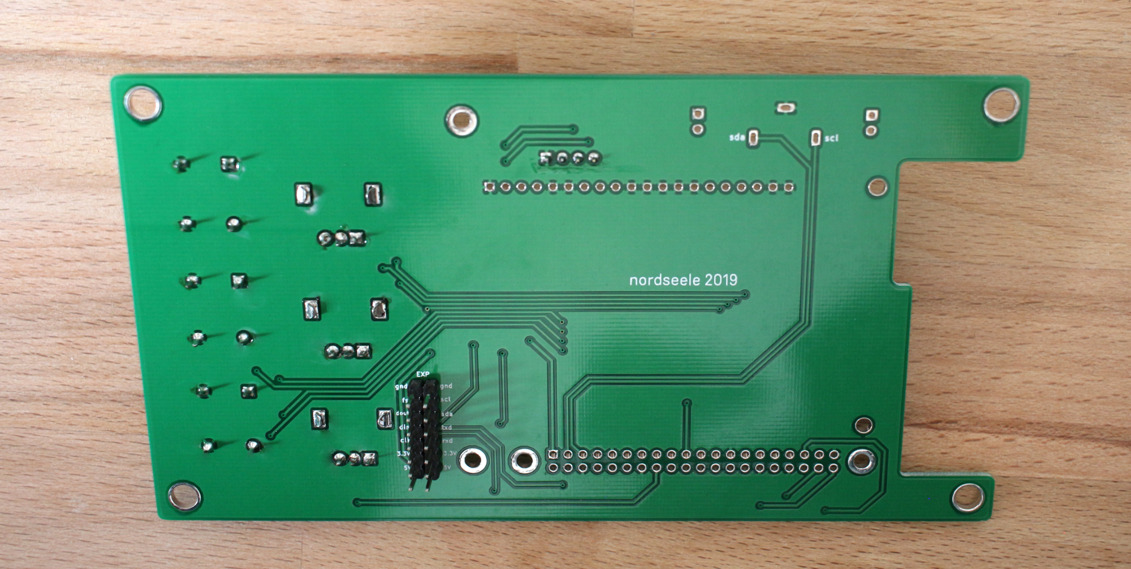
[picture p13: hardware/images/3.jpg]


On the expansion board, make sure all the jack connectors are properly aligned. The pads have been voluntarily enlarged.  

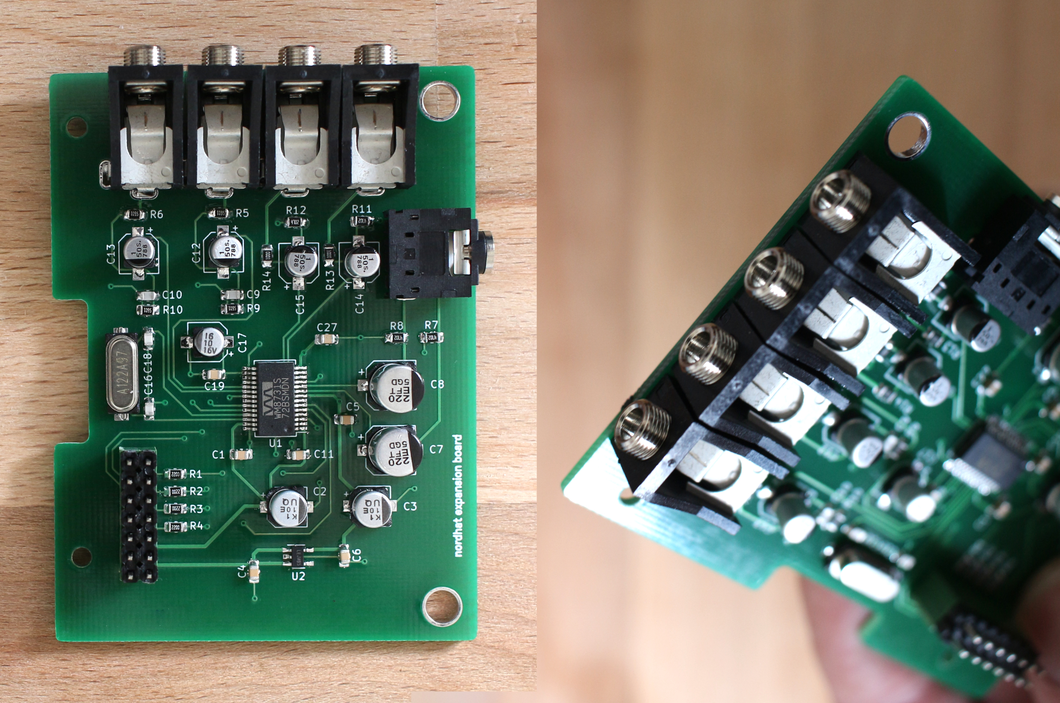
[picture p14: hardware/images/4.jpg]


Mount the HEX standoffs on the Raspberry Pi, put the header on, make sure everything is aligned and solder the J1 header to the main board. Use 3 11mm MF standoffs or 2 FF and 1 MF and a M2.5 nut for H9 (h9 is under the display but it remains accessible once the OLED is soldered on.) See photo n°9

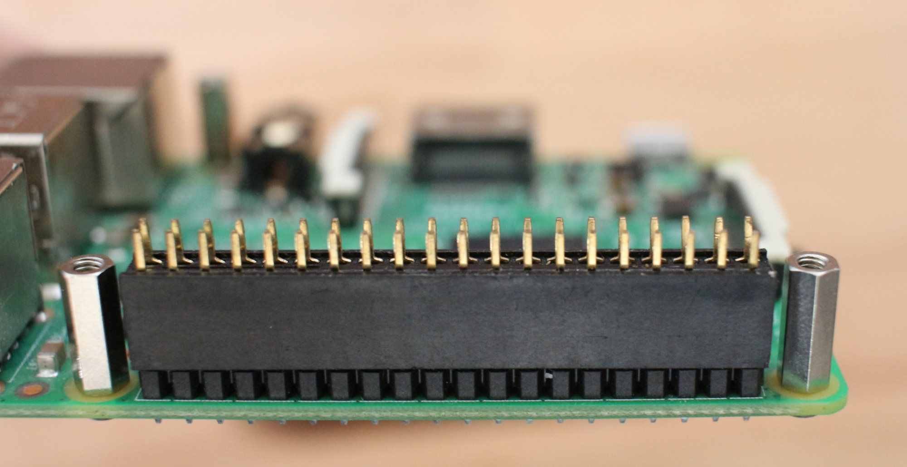
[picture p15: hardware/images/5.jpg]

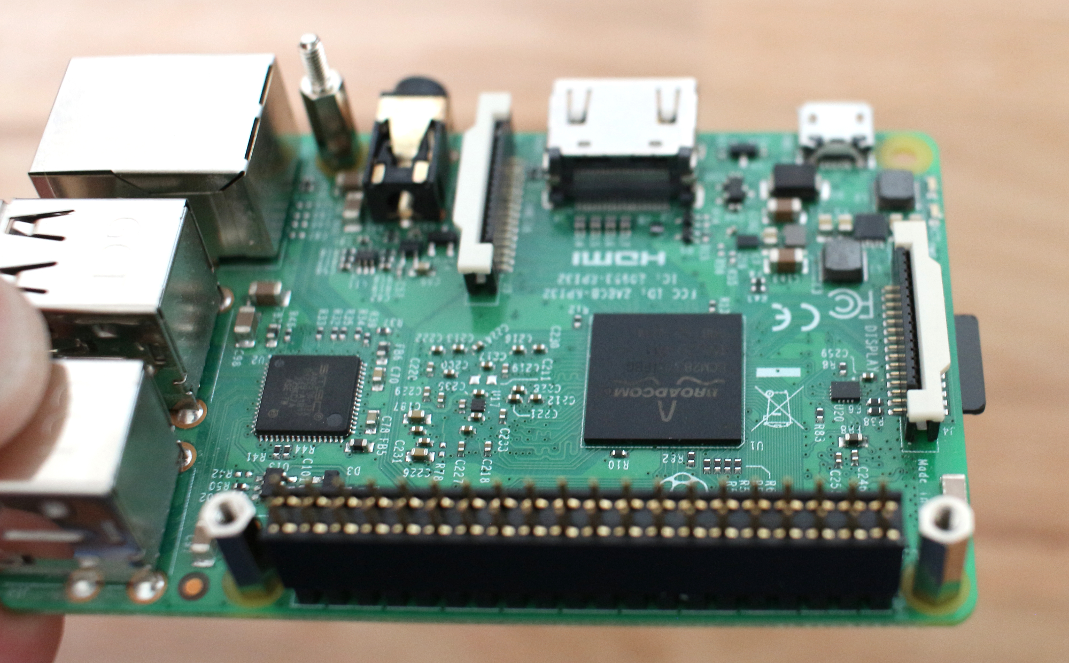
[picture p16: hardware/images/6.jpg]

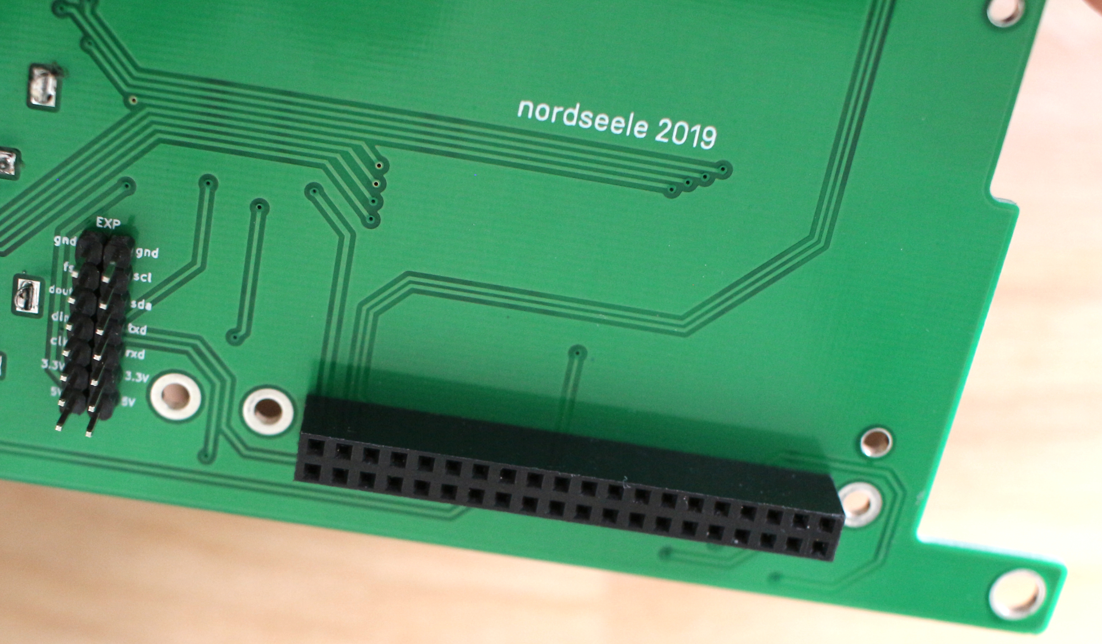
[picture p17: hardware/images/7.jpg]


Detach the Raspberry Pi and solder the OLED display. Be careful with the alignement. It will be quite difficult to reposition or desolder afterwards.

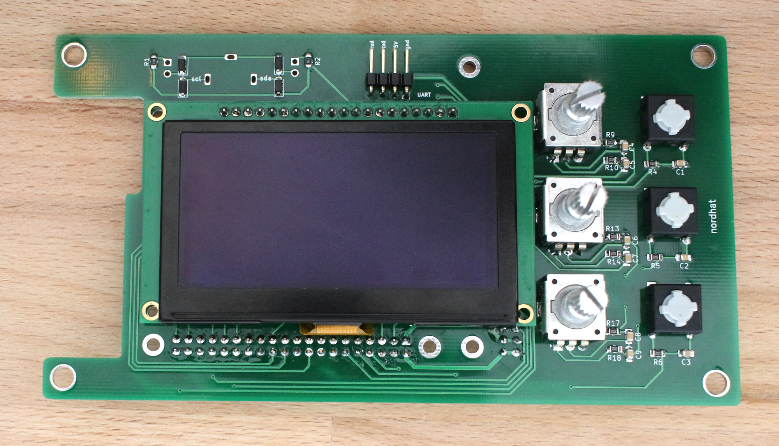
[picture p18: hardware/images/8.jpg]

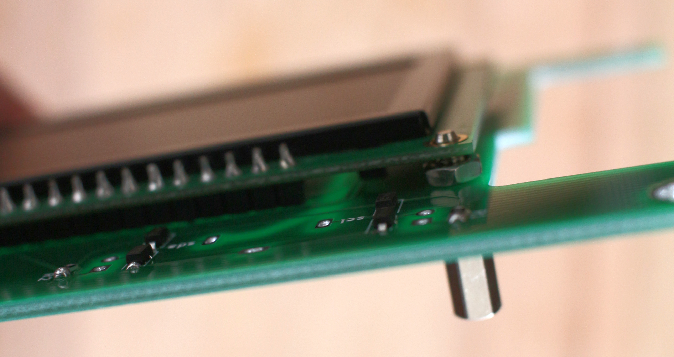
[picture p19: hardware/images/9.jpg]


You can now attach the Raspberry Pi to the main board using M2.5 screws.

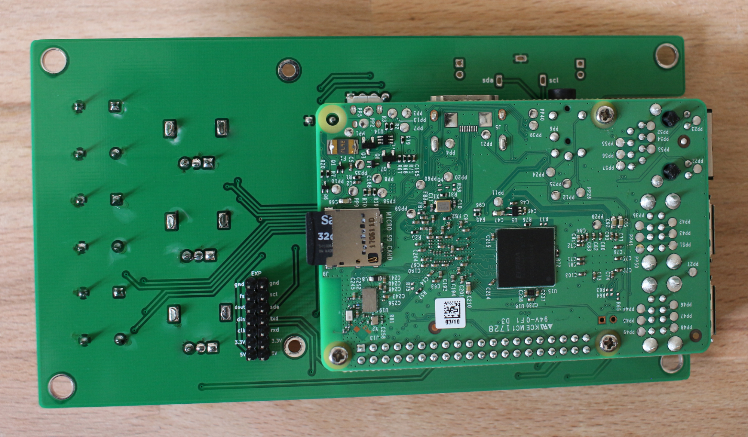
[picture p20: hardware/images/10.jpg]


## Assembling the two boards

Mount the two boards and the panels together using the standoffs and the screws. You'll need the attach the 7mm and the 10mm standoffs together using headless M3 screws.

| holes (h) | position | length  | type  | thread | quantity | sku
| :---: | :---: |:---: | :-----: | :---: | :---: | :----:
| 1, 2, 3, 4 | A | 7mm | FF  | M3 | 4 | WA-SMSI 9774070360R
| 1, 3 | D  | 15mm |  FF | M3  | 2 | WA-SMSI 9774150360R
| 5, 6  | RPI | 11mm  | FF  | M2.5 | 2 | use hex
| 9 | RPI | 11mm  | MF  | M2.5 | 1 | use hex
| 8, 7 | EXP | 10mm  | FF  | M2.5 | 2 | use hex
| 2, 4 | C | 3mm |  FF | M3  | 2 | WA-SMSI 9774030360R
| 2, 4 | B | 10mm |  FF | M3  | 2 | WA-SMSI 9774100360R

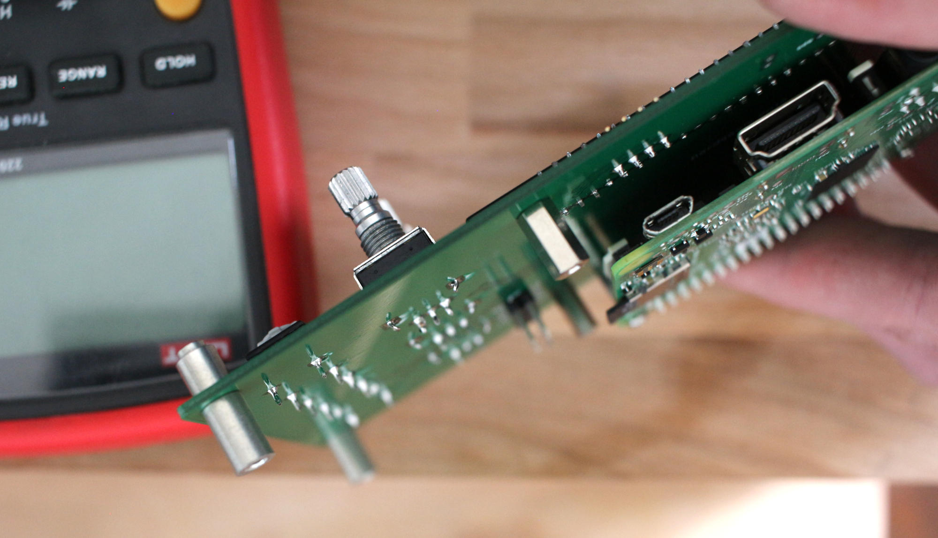
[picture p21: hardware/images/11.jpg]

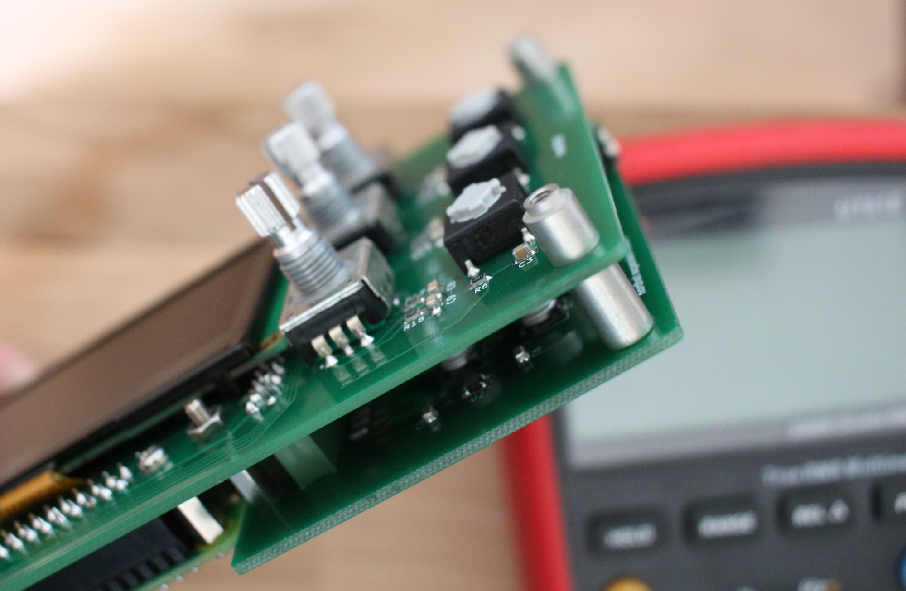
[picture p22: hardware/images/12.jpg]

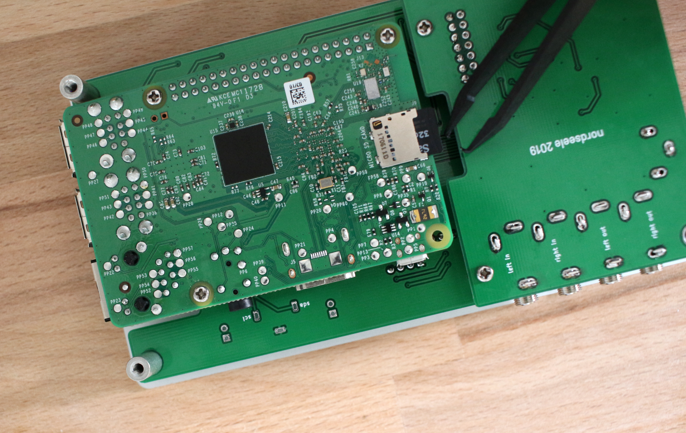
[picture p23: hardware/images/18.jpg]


Don't forget to insert the SD card. You can still access it afterwards without detaching the exp board and the RPI but you'll need to detach the bottom panel.

You might attach the 3mm standoffs to the bottom panel, it's easier like that.

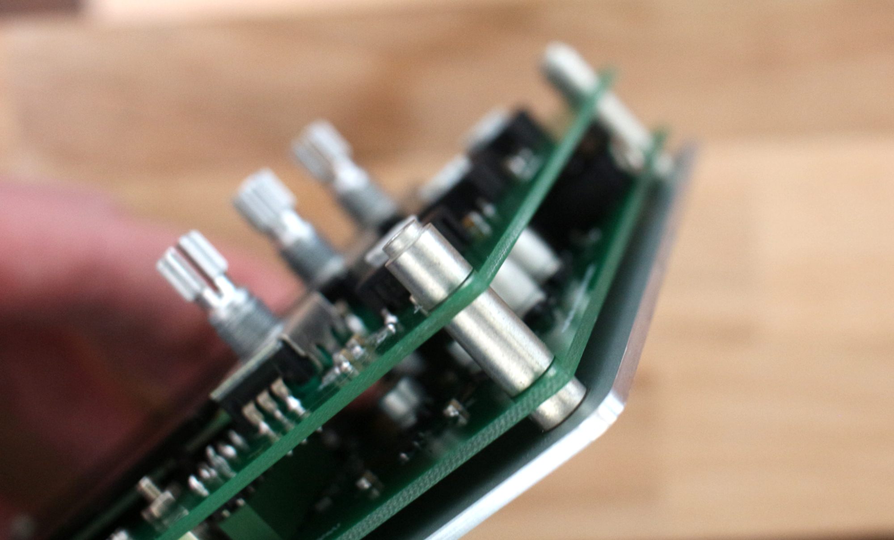
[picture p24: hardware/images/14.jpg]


"Flush cut"" the legs of the jack connectors so they don't accidentally enter in contact with the bottom panel. You might have to do the same with the legs of the butonns on main board.

Secure the exp board to the main board (h8, h78) and assemble the bottom panel.

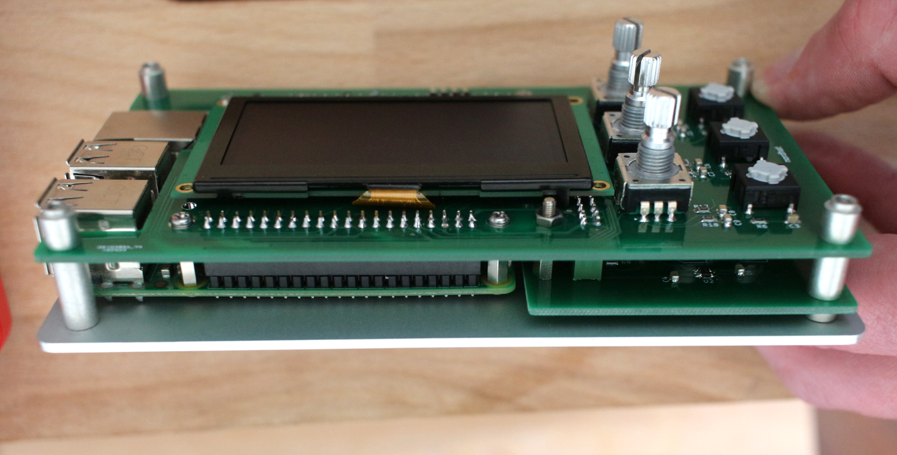
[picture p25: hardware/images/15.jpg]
Bottom panel


Place the screen protection under the top panel using double side adhesive tape.

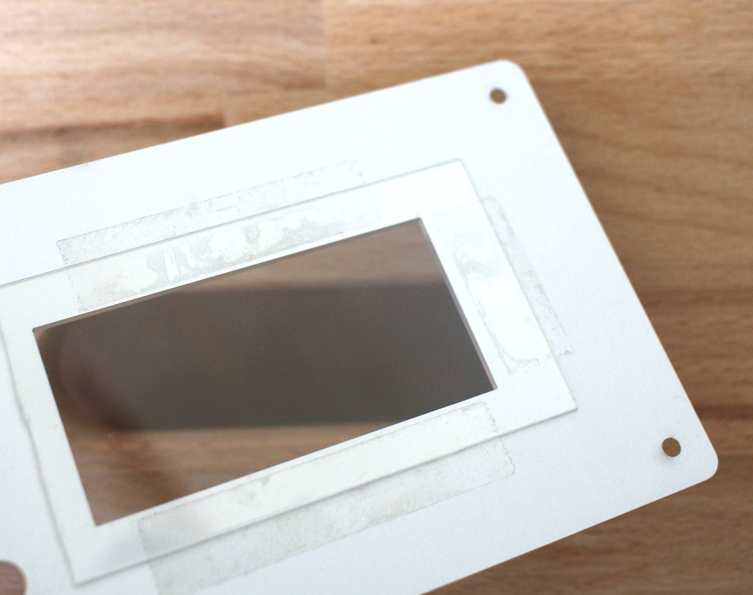
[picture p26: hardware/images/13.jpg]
Screen protection


Attach the top panel and place the button caps on the buttons.

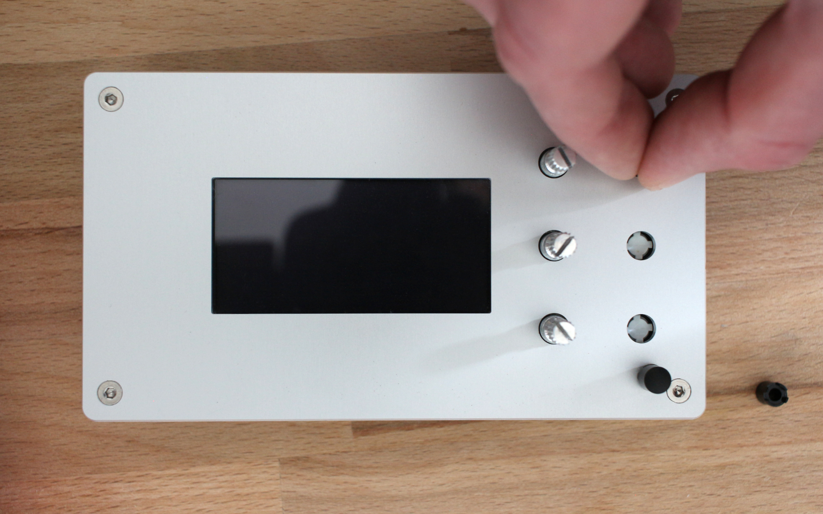
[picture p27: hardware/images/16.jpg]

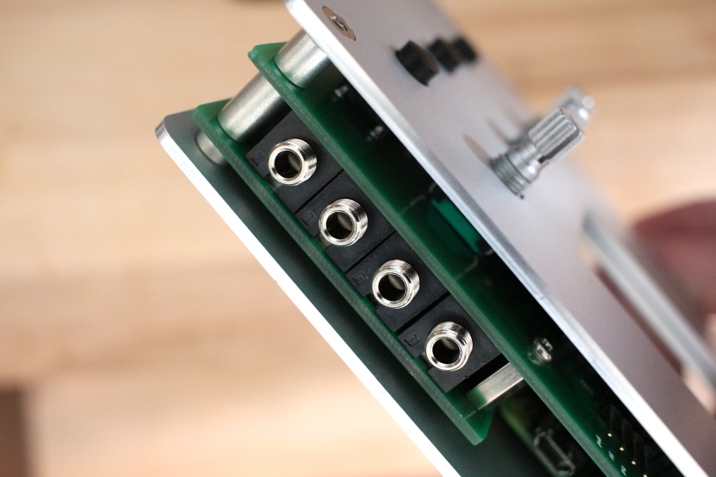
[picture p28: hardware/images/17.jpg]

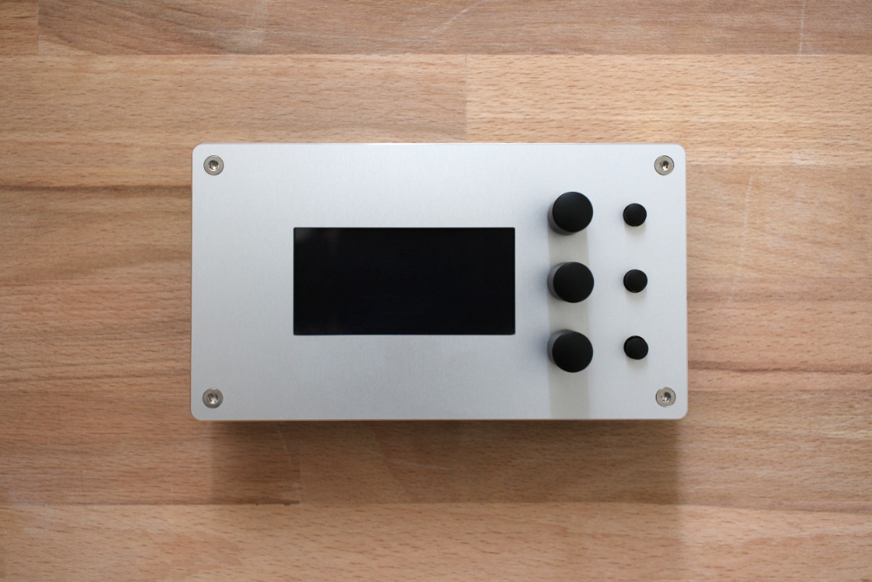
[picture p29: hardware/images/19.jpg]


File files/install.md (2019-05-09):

Overlays & config.txt available in this folder

---

or full install + optional Norns install available here
https://github.com/nordseele/nordhat_install

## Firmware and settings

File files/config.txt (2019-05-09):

# For more options and information see
# http://rpf.io/configtxt
# Some settings may impact device functionality. See link above for details

# uncomment if you get no picture on HDMI for a default "safe" mode
#hdmi_safe=1

# uncomment this if your display has a black border of unused pixels visible
# and your display can output without overscan
#disable_overscan=1

# uncomment the following to adjust overscan. Use positive numbers if console
# goes off screen, and negative if there is too much border
#overscan_left=16
#overscan_right=16
#overscan_top=16
#overscan_bottom=16

# uncomment to force a console size. By default it will be display's size minus
# overscan.
#framebuffer_width=1280
#framebuffer_height=720

# uncomment if hdmi display is not detected and composite is being output
#hdmi_force_hotplug=1

# uncomment to force a specific HDMI mode (this will force VGA)
#hdmi_group=1
#hdmi_mode=1

# uncomment to force a HDMI mode rather than DVI. This can make audio work in
# DMT (computer monitor) modes
#hdmi_drive=2

# uncomment to increase signal to HDMI, if you have interference, blanking, or
# no display
#config_hdmi_boost=4

# uncomment for composite PAL
#sdtv_mode=2

#uncomment to overclock the arm. 700 MHz is the default.
#arm_freq=800

# Uncomment some or all of these to enable the optional hardware interfaces
#dtparam=i2c_arm=on
#dtparam=i2s=on
dtparam=spi=on
dtoverlay=i2s-mmap

enable_uart=1

# DAC audio
dtoverlay=rpi-proto

# Uncomment this to enable the lirc-rpi module
#dtoverlay=lirc-rpi

# Correct console for MacOS
dtoverlay=pi3-disable-bt
systemctl disable hciuart

# Additional overlays and parameters are documented /boot/overlays/README

# Enable audio (loads snd_bcm2835)
dtparam=audio=off

dtoverlay=buttons-encoders
dtoverlay=ssd1322-spi
gpio=6,27,23=pu

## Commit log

2019-04-11 first upload
    [config.txt]
2019-04-16 added main board BOM
    [BOM_nornsHat.csv]
2019-04-16 renamed a couple of files
    [nordsHat_bottom_alu.dxf, nordsHat_top_alu.dxf]
2019-04-16 rebranded and adjusted paths
    [BOM_expansion_board.csv, BOM_nornsHat.csv, config.txt]
2019-04-17 corrected paths
    [config.txt, nordhat_bottom_alu.dxf, nordhat_top_alu.dxf]
2019-04-18 added notes and complete BOM
    [BOM_expansion_board.csv, BOM_mainboard.csv]
2019-04-18 added oled header
    [BOM_mainboard.csv]
2019-04-18 mod bom first line
    [BOM_expansion_board.csv]
2019-04-18 added mockup of standoffs
